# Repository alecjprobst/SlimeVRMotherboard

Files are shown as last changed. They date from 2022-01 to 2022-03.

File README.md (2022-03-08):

# SlimeVR Motherboard

This is a project to make it easier to create SlimeVR trackers. This project reduces the amount of cable management needed when making SlimeVR trackers by providing a PCB that can be made for only $2. Beginner instructions on how to buy a PCB are below. Total cost should be around $55-60 for an enhanced core set excluding the cost of cases and straps.

# Sections

 - Parts and Setup
 - PCB Files and Submission
 - STL Files and Description
 - Assembly Instructions

## Parts and Setup

These PCB's use the official SlimeVR [Components](https://docs.slimevr.dev/diy/components-guide.html) and [Tracker Schematics](https://docs.slimevr.dev/diy/tracker-schematics.html). The PCB is compatible with either the BNO08X or MPU6050 IMU's and has locations for optional Battery Sense resistors and Charge Diodes. With this PCB, you will only need wire for connecting the IMU's. 

All of the parts below are linked in the SlimeVR [Components](https://docs.slimevr.dev/diy/components-guide.html) guide.
This PCB is made for use with the following parts:

 - D1 Mini
 - TP4056 Charging Board (any connector)
 - 3.7V Batteries
 - SS22F32 DPDT Switch
 - Either BNO08X or MPU6050 IMU's
 - (Optional) 180k ohm Battery Sense Resistor
 - (Optional) 1N5817 Charge Diodes

3D printable cases for the SlimeVR Trackers are included in this repo. They require no supports and no hardware to put together. See the STL Files and Description below

## PCB Files

All PCB files are included in this repo in the KiCAD Schematic Folder. Please feel free to modify them as you see fit. KiCAD was use to create this project which is a free and opensource tool to create PCB's. 

## PCB Submission 

Buying a PCB is very simple. Download this repo by clicking the green "Code" button towards the top of this page then click "Download ZIP". You will start downloading a ZIP file contain this entire repo. Open the zip file and find the "SlimeVR Motherboard Gerbers V1.2.rar" and "JLCPCB_Upload_Settings.png" file. Drag these to your desktop or a folder of your choice. 

To buy the PCB, we will use JLC PCB. Their website can be found here: https://jlcpcb.com/. Click on the text that says "Add gerber file" and find and select the "SlimeVR Motherboard Gerbers V1.2.rar" you just moved. Open the "JLCPCB_Upload_Settings.png" file and make sure the settings between the picture and what jlcpcb have shown you are the same. Feel free to change the PCB color to whatever you like (purple looks great!). Click "Save to Cart" then buy your PCB's. This process should be the same as any other online purchase from here on out.

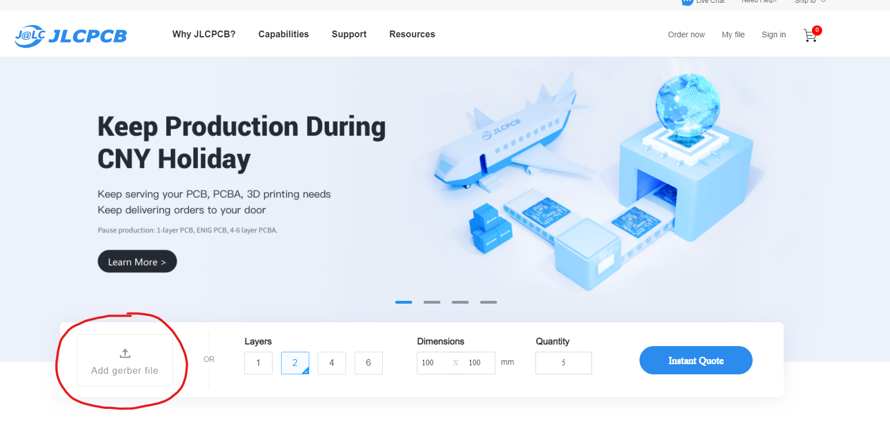
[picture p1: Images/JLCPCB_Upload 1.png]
Images/JPCPCB_Upload 1.png


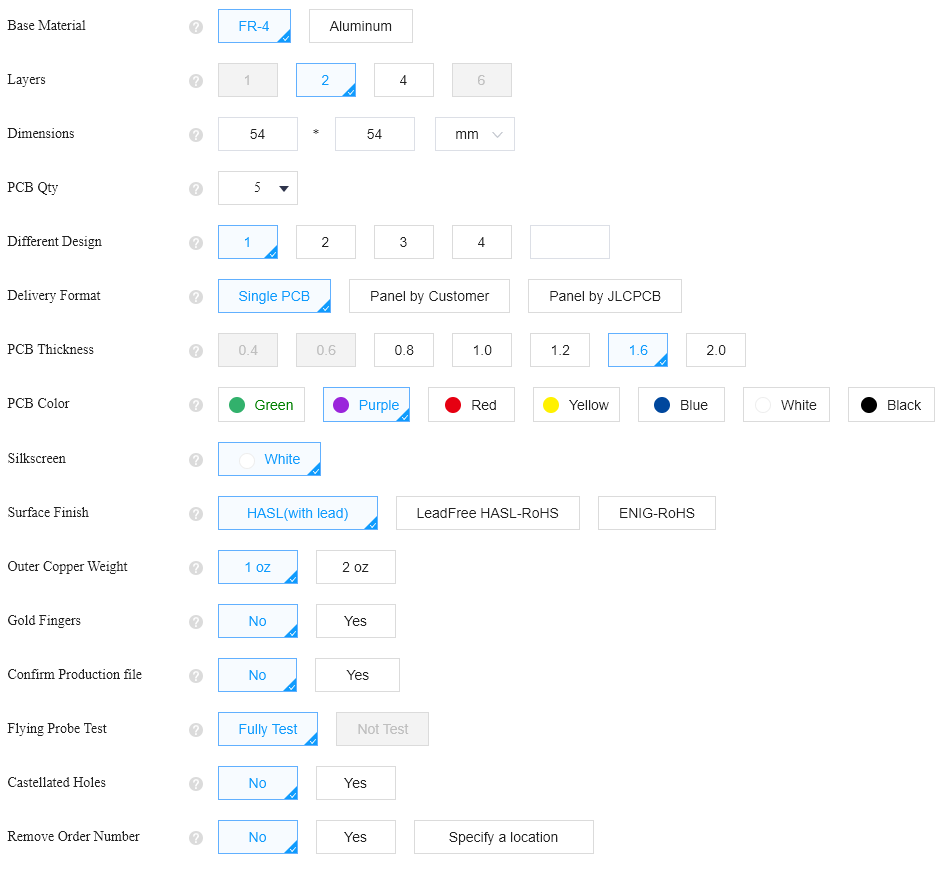
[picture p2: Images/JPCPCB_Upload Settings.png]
Images/JLCPCB_Upload Settings.png


## STL Files and Description

All STL's were created in Fusion360. Please feel free to modify them as you see fit. If you do not have a 3D printer, you can print the cases from jcpcb or you may want to consider 3D printing sites like [Hubs](https://www.hubs.com/3d-printing/) or [Sculpteo](https://www.sculpteo.com/en/).

Cases can be printed on an FDM printer at .2mm layer height.

A single SlimeVR Tracker case requires two parts, a Higher_Body.stl and a Lower_Body.stl. Both of these parts can be printed without supports. The Lower_Body.stl has poles to mount the PCB inside of the case so it does not shake. It is recommended to add hot glue to make sure the PCB does not move at all. Both cases have holes for charging and access to the D1 Mini as well as the switch and AUX tracker cable. The cases should slide together after being printed and should be somewhat difficult to pull apart.

## Assembly Instructions
A Knolled layout of all parts needed for one tracker is shown in this picture. Please note that your IMU's may look different and the resistor and diodes are optional.

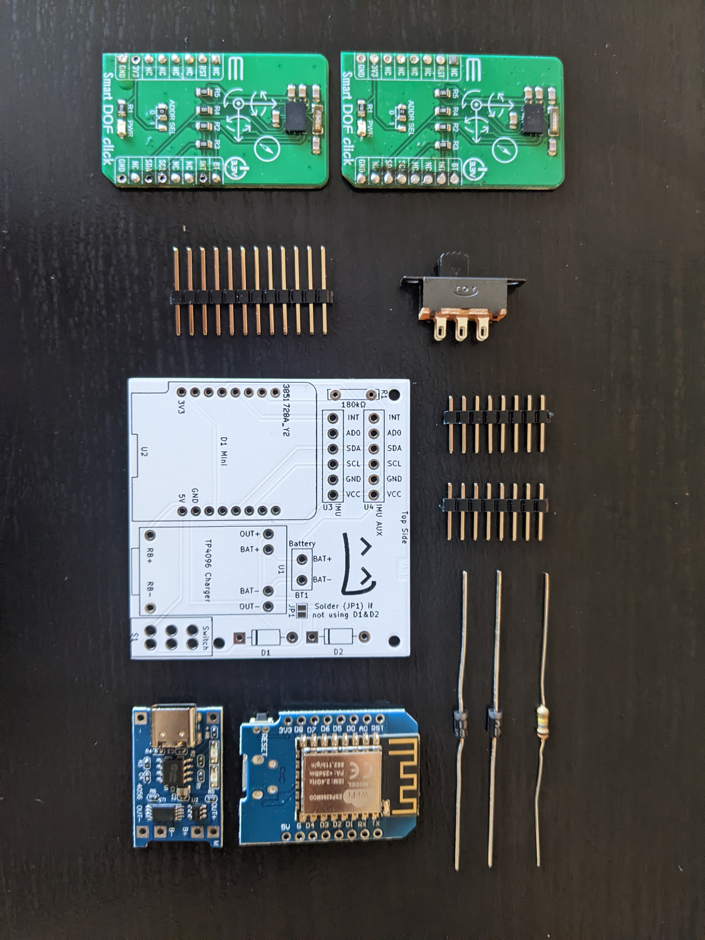
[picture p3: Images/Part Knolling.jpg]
Images/Part Knolling.jpg


To place the resistors, first bend them as shown below

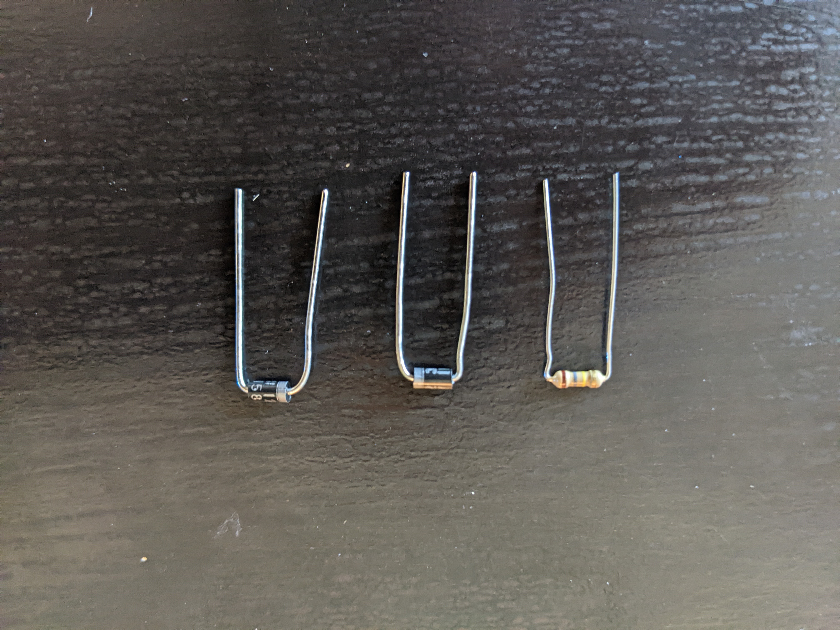
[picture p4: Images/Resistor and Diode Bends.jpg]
Image/Resistor and Diode Bends.jpg


Place these resistor and diodes as such

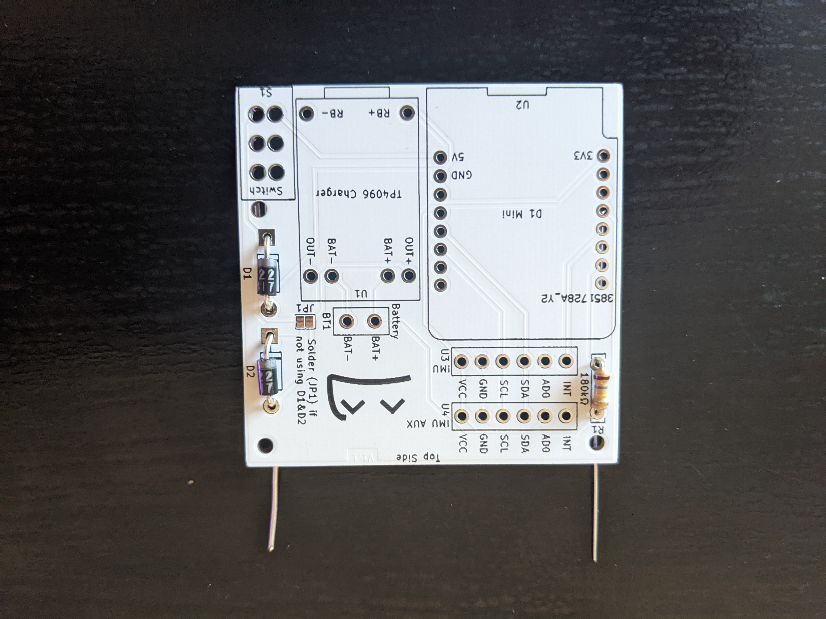
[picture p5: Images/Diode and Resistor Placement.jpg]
Images/Diode and Resistor Placement.jpg


Solder the resistor and diodes as shown in the images below. Cut the excess wire when finished soldering.

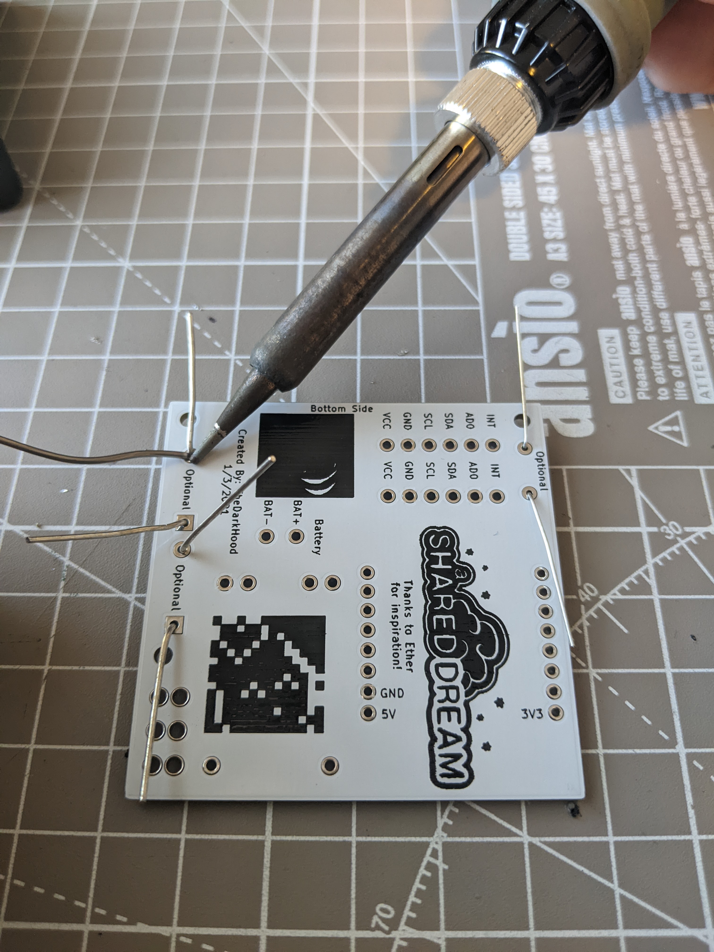
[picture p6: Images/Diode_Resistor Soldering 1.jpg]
Images/Diode_Resistor Soldering 1.jpg


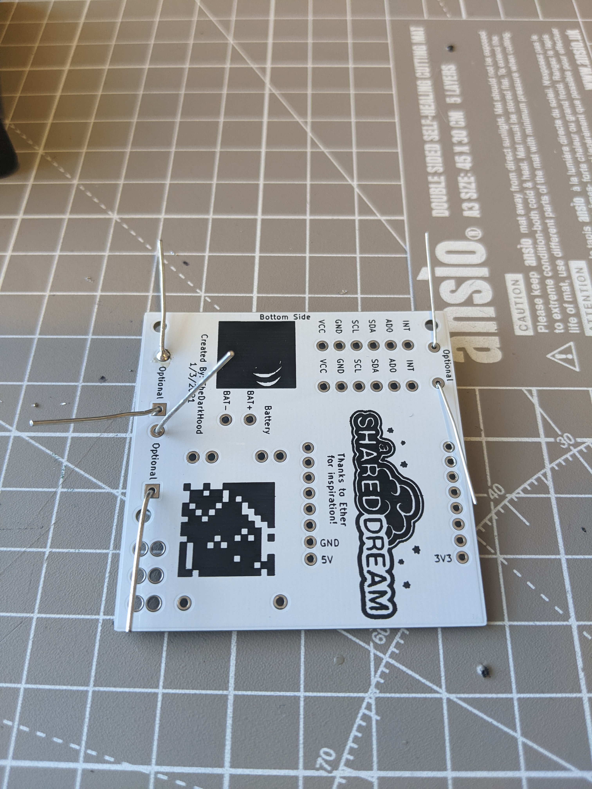
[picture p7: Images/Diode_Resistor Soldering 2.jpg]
Images/Diode_Resistor Soldering 2.jpg


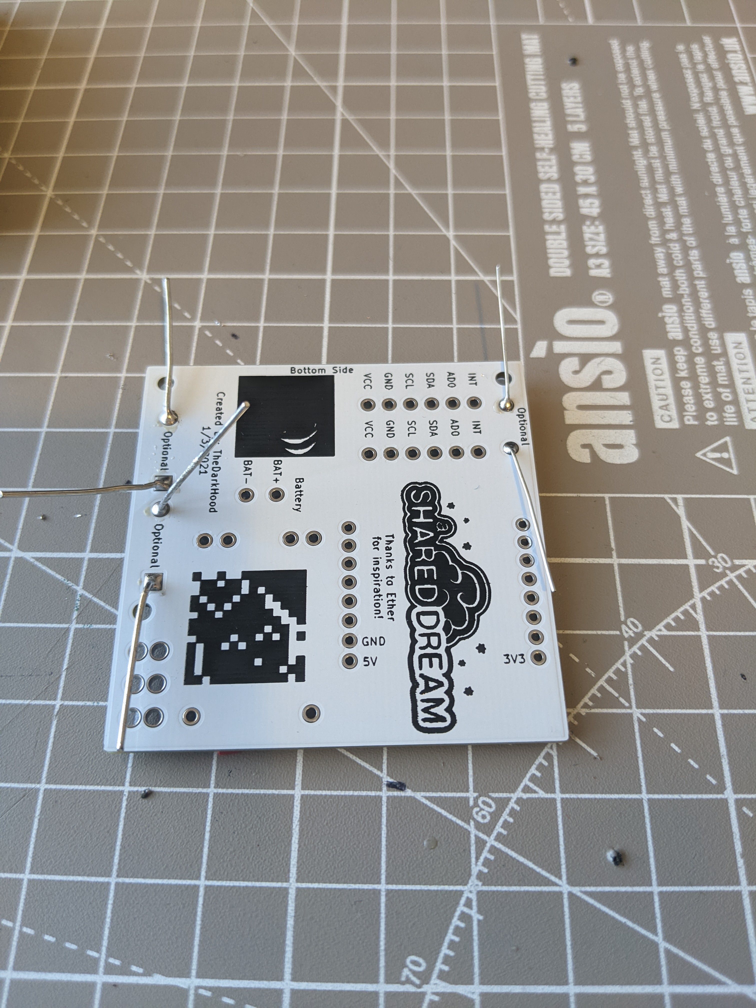
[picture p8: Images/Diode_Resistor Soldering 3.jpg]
Images/Diode_Resistor Soldering 3.jpg


Images/Diode_Resistor Soldering 4.jpg

To solder the TP4096, take 6 pins and place them as such

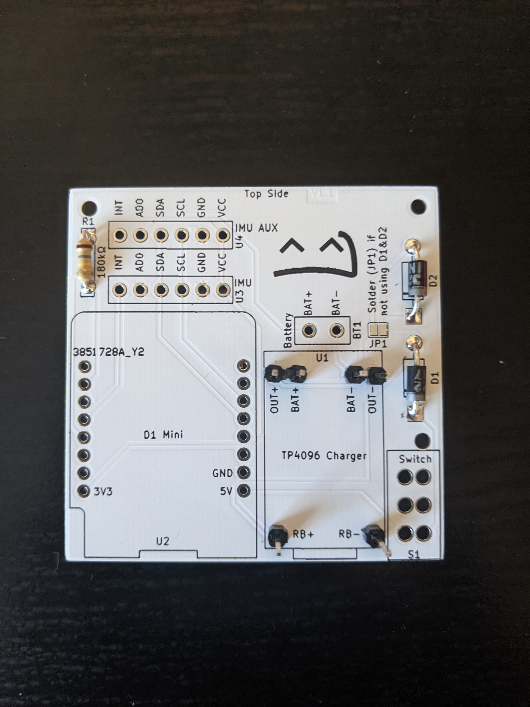
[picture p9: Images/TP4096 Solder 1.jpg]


Solder them on both the top of the TP4096 and the bottom of the PCB as shown below. Cut the excess pins on the top and bottom when finished soldering.

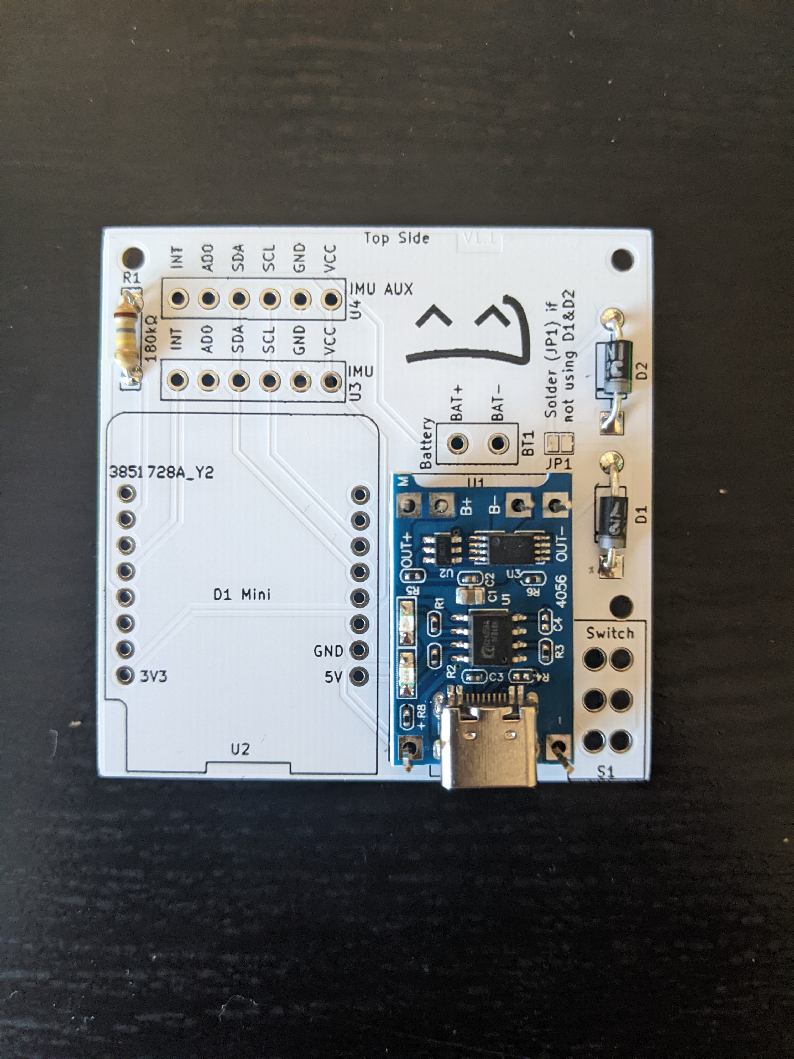
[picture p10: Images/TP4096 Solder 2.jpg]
Images/TP4096 Solder 2.jpg


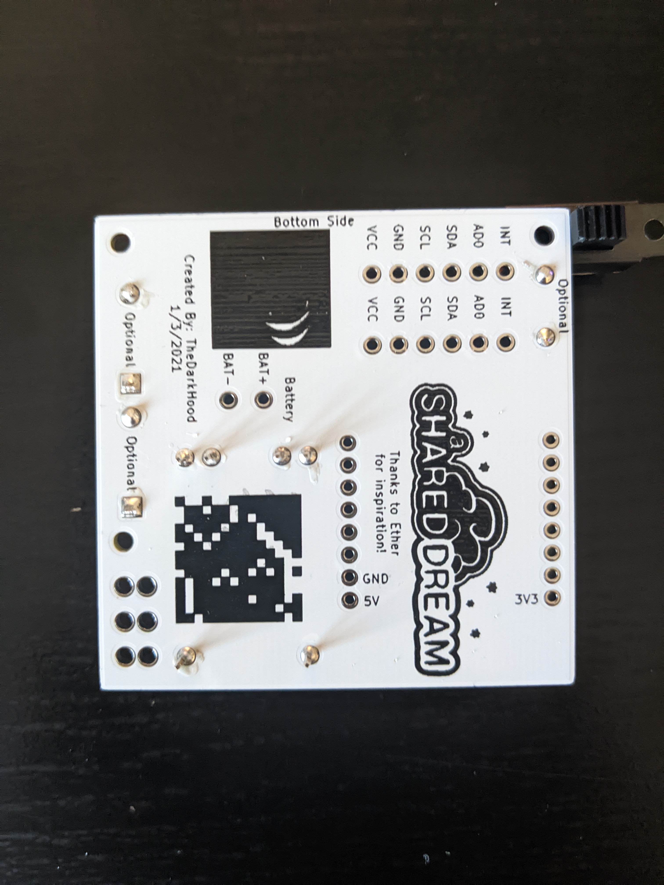
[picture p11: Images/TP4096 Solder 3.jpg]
Images/TP4096 Solder 3.jpg


To solder the D1 Mini, place two 1x8 pins in the holes as shown below.

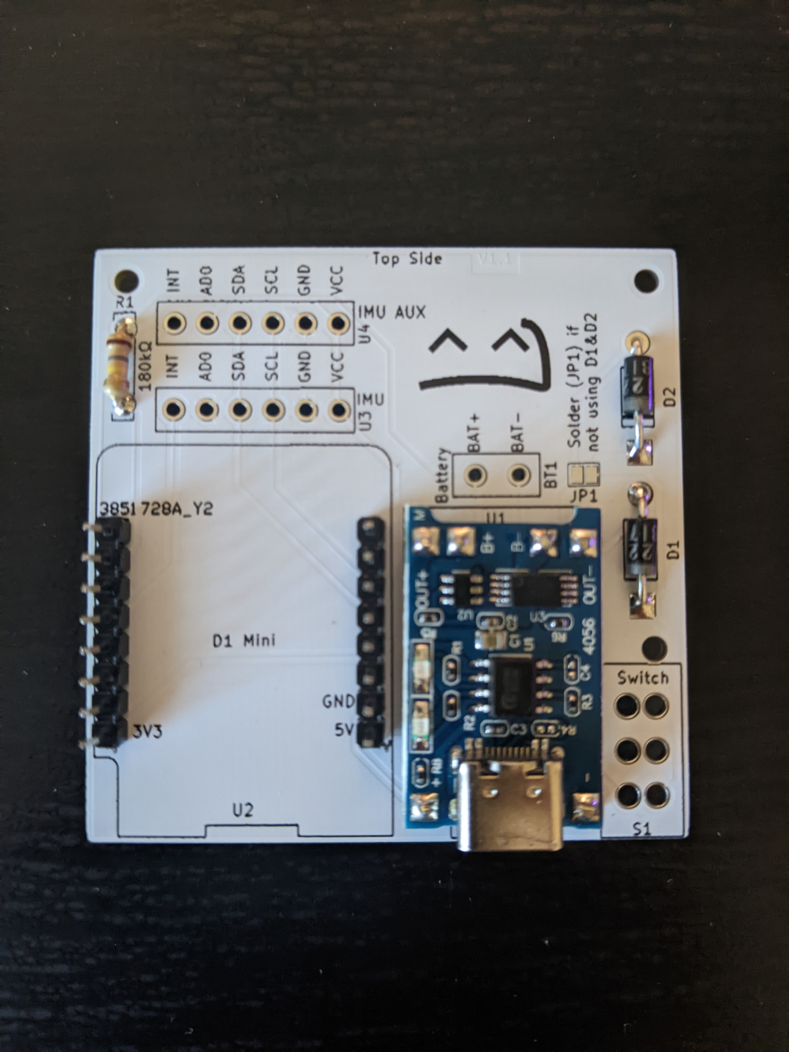
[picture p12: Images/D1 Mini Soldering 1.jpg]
Images/D1 Mini Soldering 1.jpg


Solder the top of the D1 Mini and bottom of the PCB as shown below. Cut the excess pins on the top and bottom when finished soldering.

Images/D1 Mini Soldering 2.jpg

Images/D1 Mini Soldering 3.jpg

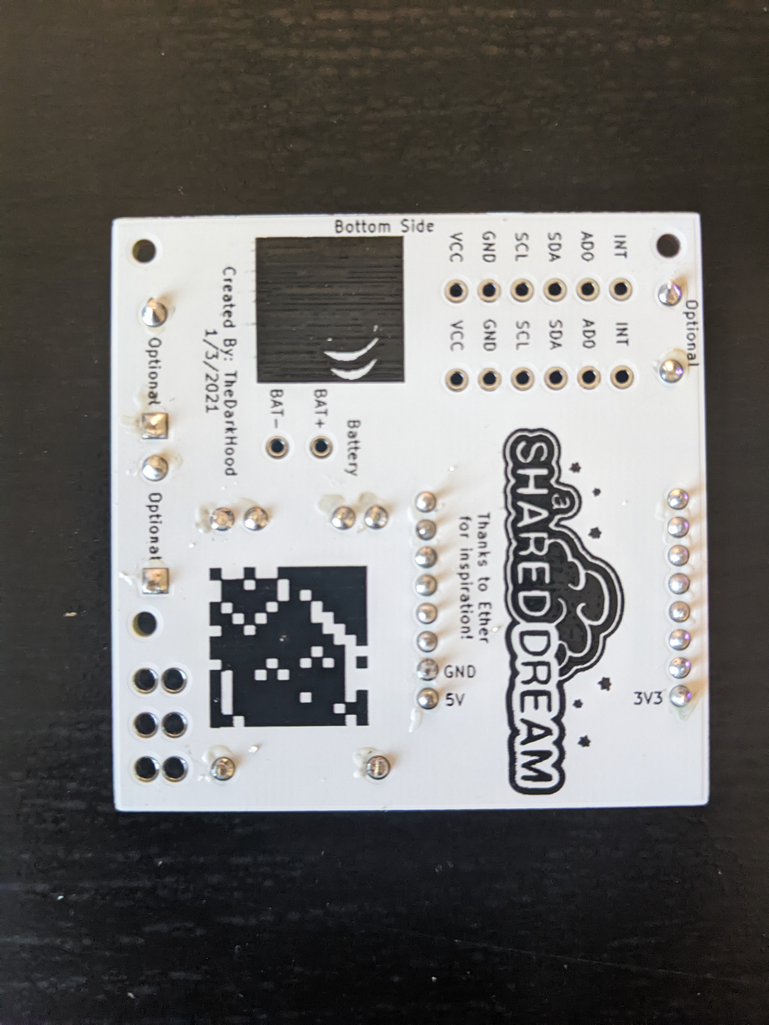
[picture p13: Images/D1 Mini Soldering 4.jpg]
Images/D1 Mini Soldering 4.jpg


Before soldering the switch, cut the excess hole mount as shown in the before and after pictures below.

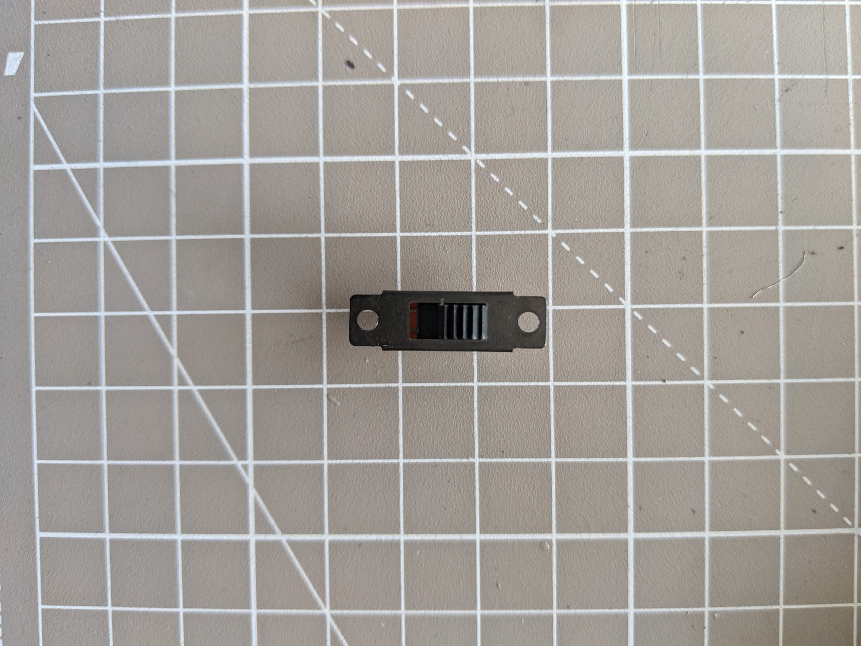
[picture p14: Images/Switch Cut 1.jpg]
Images/Switch Cut 1.jpg


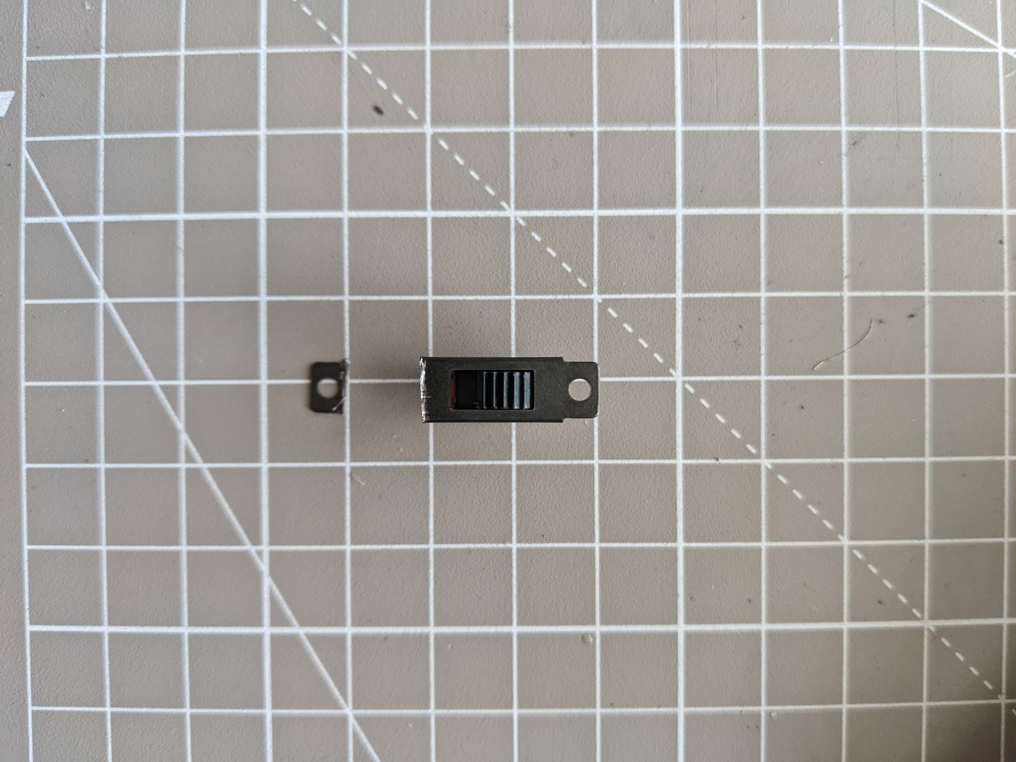
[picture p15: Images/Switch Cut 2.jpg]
Images/Switch Cut 2.jpg


To keep the Switch in place, it is recommended to use tape as shown below. Once secured, solder the switch from the bottom of the PCB. Cut the excess switch contacts after soldering

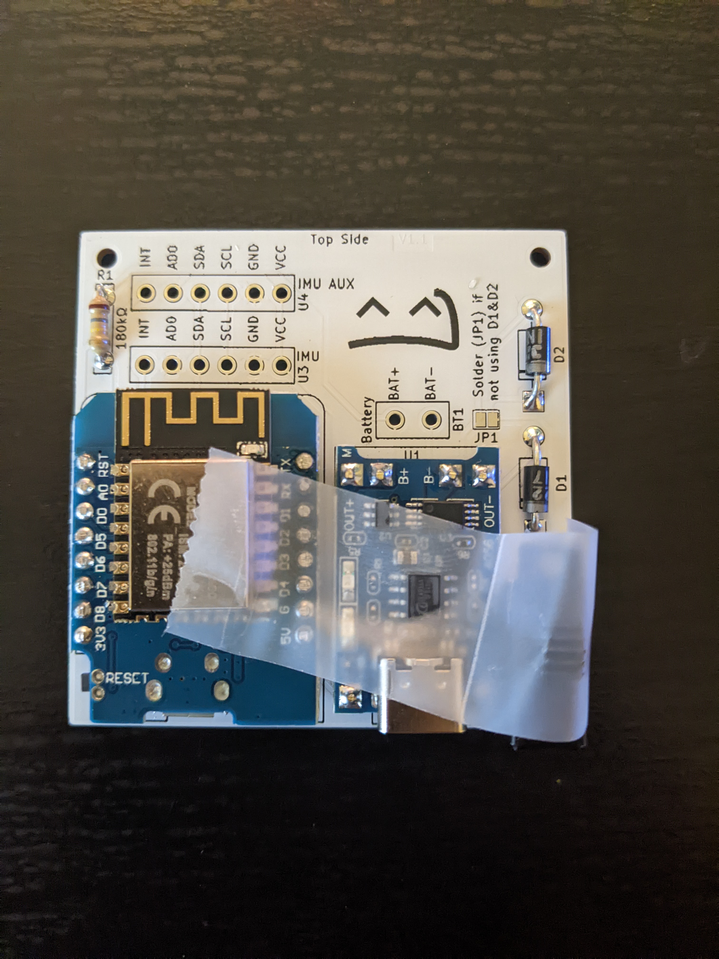
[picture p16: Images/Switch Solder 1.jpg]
Images/Switch Solder 1.jpg


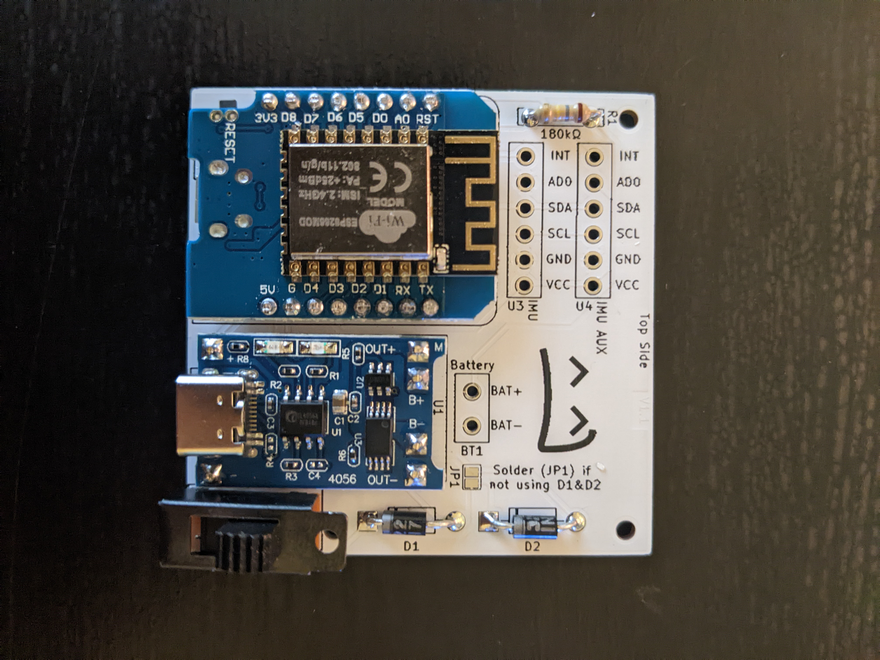
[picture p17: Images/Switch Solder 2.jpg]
Images/Switch Solder 2.jpg


To add the IMU, first cut out 6 wires of around 25mm long and strip the ends of the wires as shown below.

Images/IMU Wiring.jpg

Solder the wires as shown below. Generally it is easier to solder to the PCB first then the IMU but this may be personal preference. Cut the excess wire after soldering. Note: the AD0 wire is missing in the two pictures below and is required.

Images/IMU Soldering 1.jpg

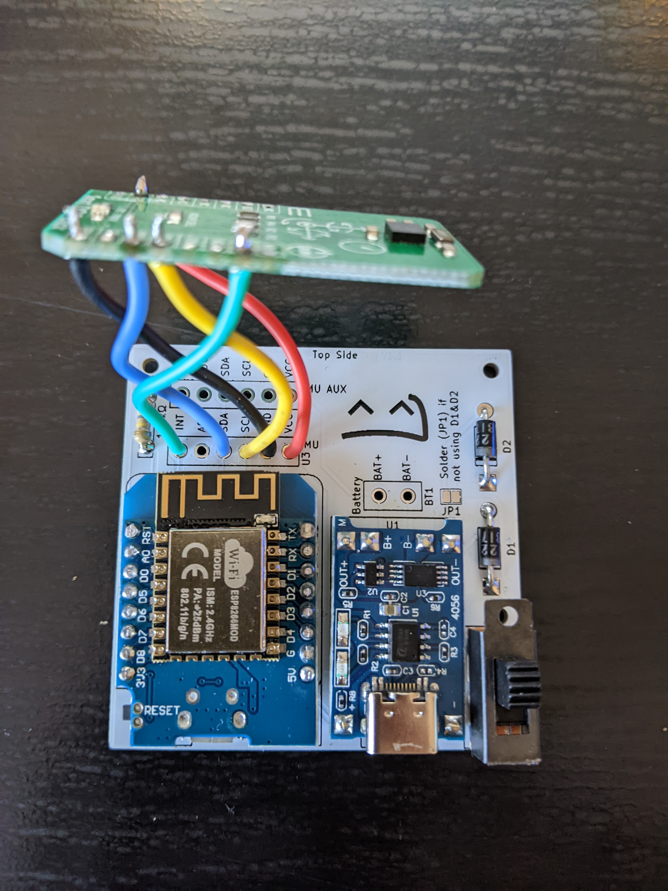
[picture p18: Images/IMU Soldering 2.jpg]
Images/IMU Soldering 2.jpg


To Solder the AUX IMU, cut out 6 wires of either 150mm or 300mm in length. The 150mm is used for the ankle/foot IMU's while the 300mm is used for the chest/wait IMU's.

Images/AUX IMU Wiring.jpg

Solder the AUX IMU as shown below. Cut the excess wires after soldering.

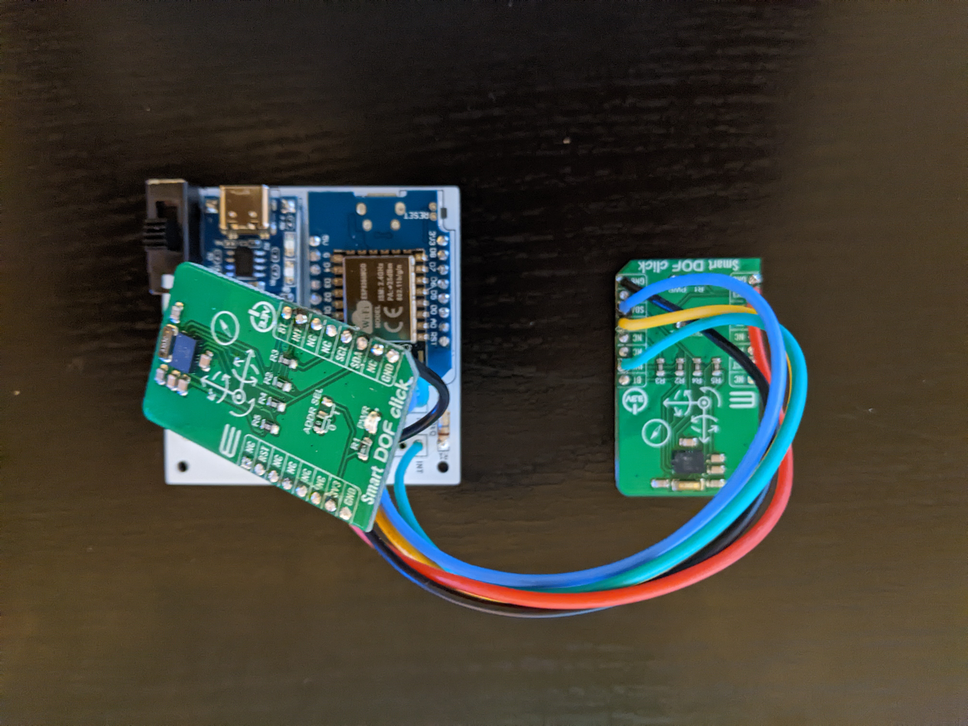
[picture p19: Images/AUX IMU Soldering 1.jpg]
Images/AUX IMU Soldering 1.jpg


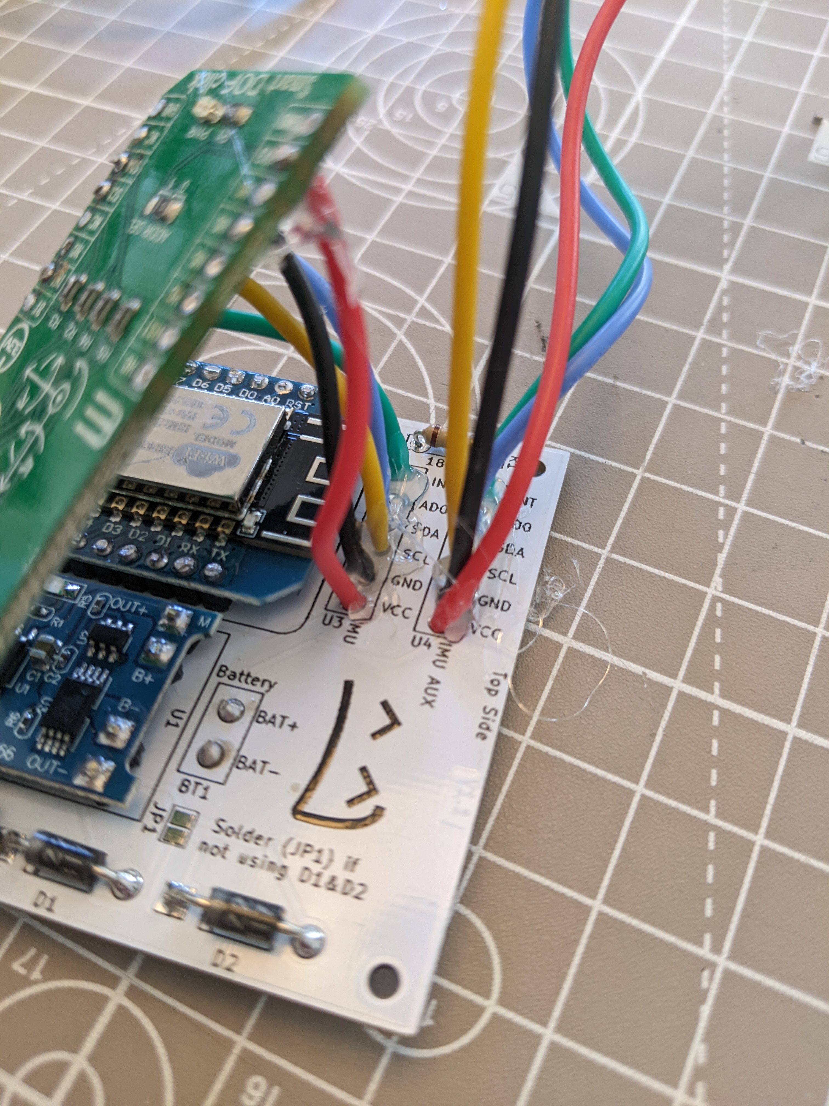
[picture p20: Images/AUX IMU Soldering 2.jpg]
Images/AUX IMU Soldering 2.jpg


To solder the battery, solder the ground (black) wire first then the power (red) wire second from the bottom of the PCB. Make sure these wires do not touch as it may cause sparks. Cut the excess wire when finished soldering.

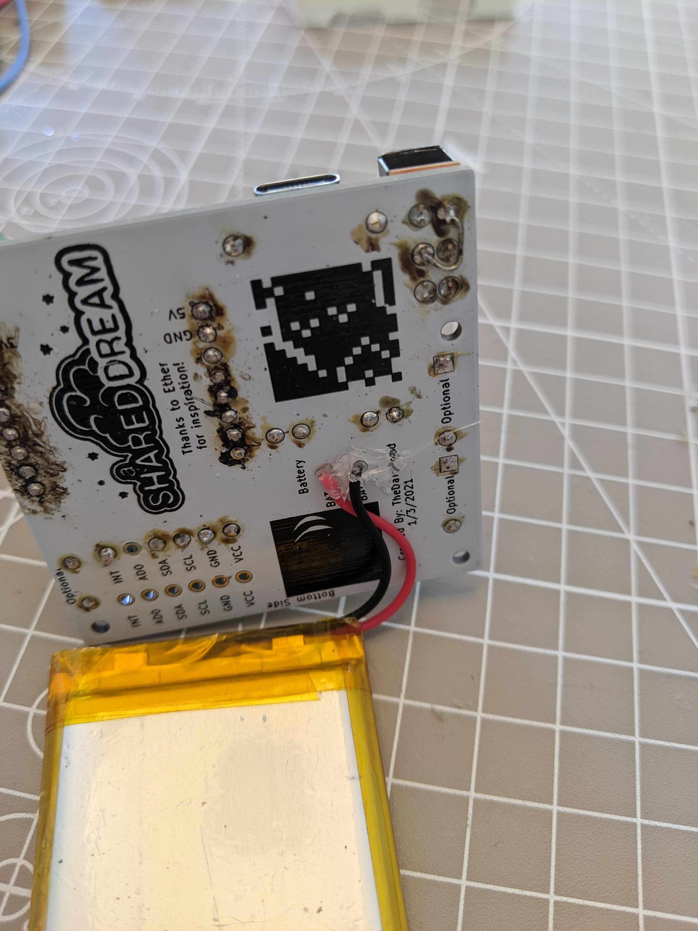
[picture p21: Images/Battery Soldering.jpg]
Images/Battery Soldering.jpg


It is recommended but not required to hot glue all parts as to prevent parts from moving inside the case. Hot gluing the wires will help protect from from strain as well. To assemble the case, put the battery in the Lower Body first.

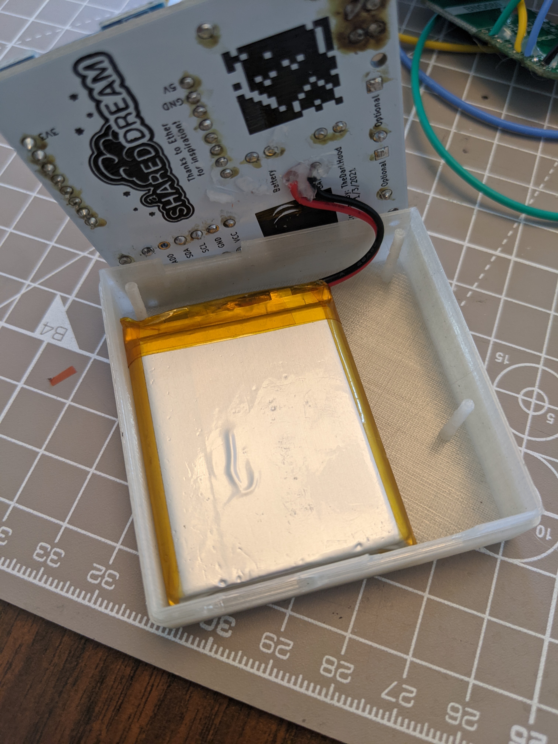
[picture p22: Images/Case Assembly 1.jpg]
Images/Case Assembly 1.jpg


Next, put the PCB on top of the battery with the ports facing the holes. The holes in the PCB should keep the PCB in place. Make sure that there are no excess wires or pins poking into the battery.

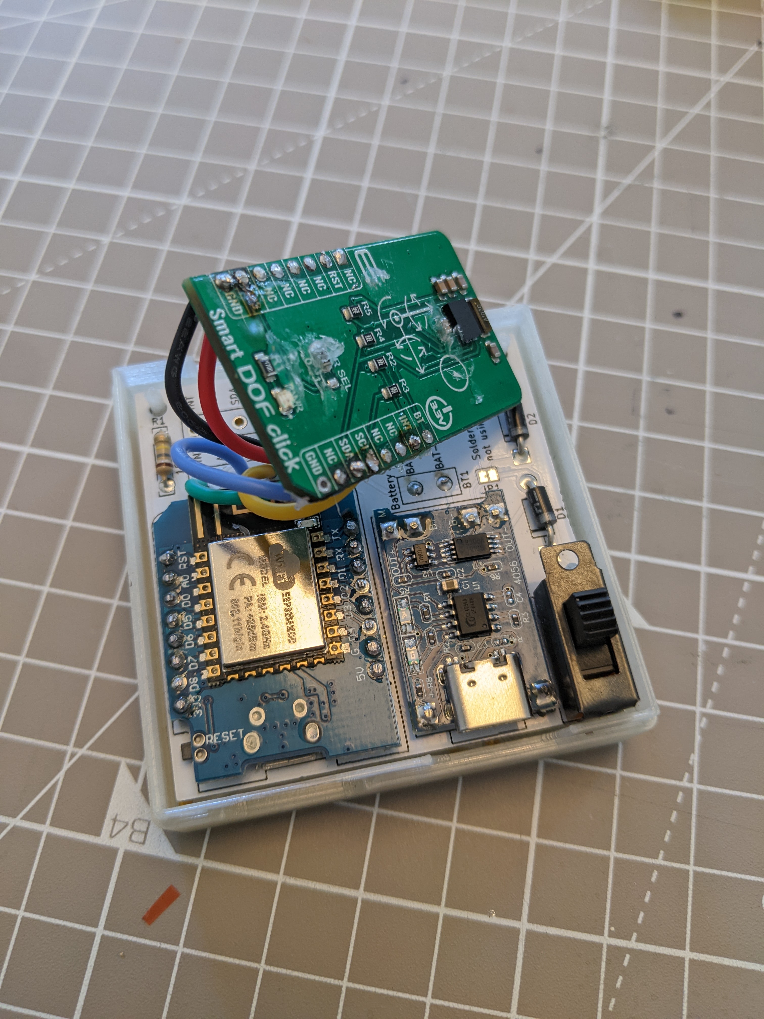
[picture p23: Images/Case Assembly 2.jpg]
Images/Case Assembly 2.jpg


Hot glue the IMU to the Higher Body Case. Make sure the Higher Body Case is lined up correctly so the holes are facing the correct direction. 

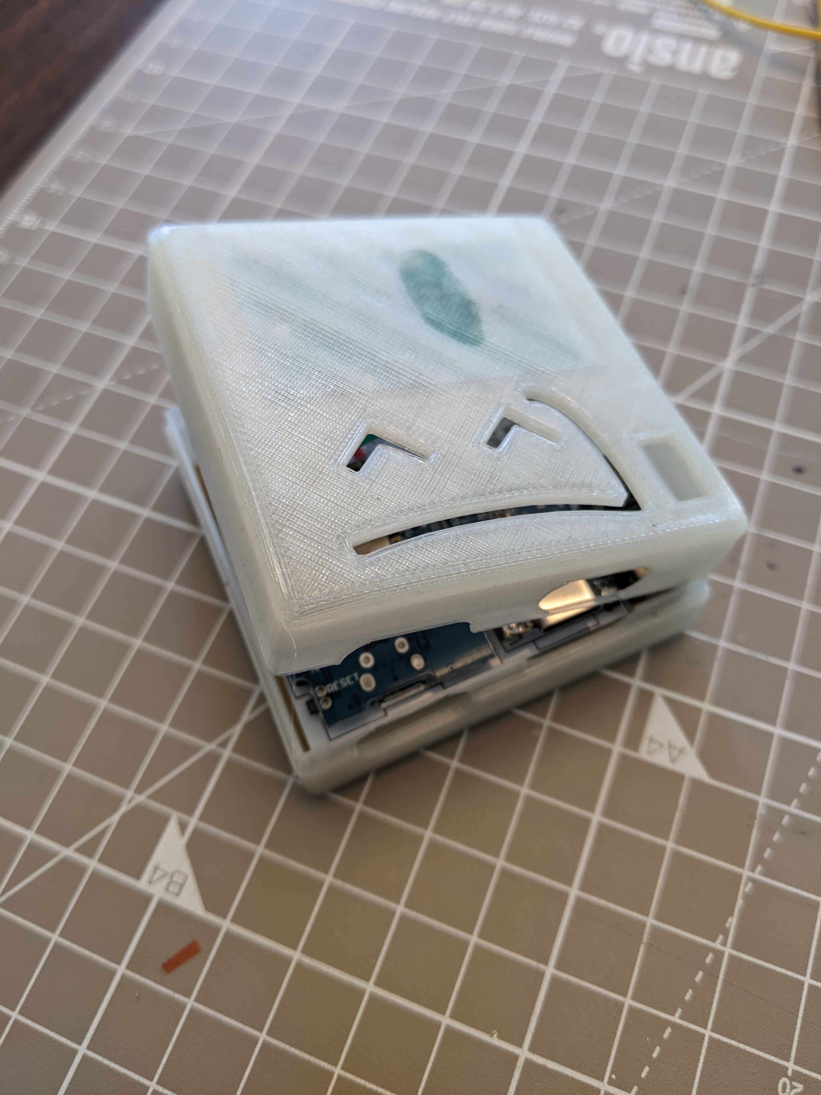
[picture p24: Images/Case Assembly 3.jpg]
Images/Case Assembly 3.jpg


Slide the Higher Body Case onto the Lower Body Case to close the SlimeVR Tracker. Make sure no wires get pinched or disconnected and the switch is able to be turned off and on. This completes the hardware assembly of the SlimeVR trackers. To setup the software, continue from the [SlimeVR Tracker Firmware Guide](https://docs.slimevr.dev/firmware/updating-firmware.html)

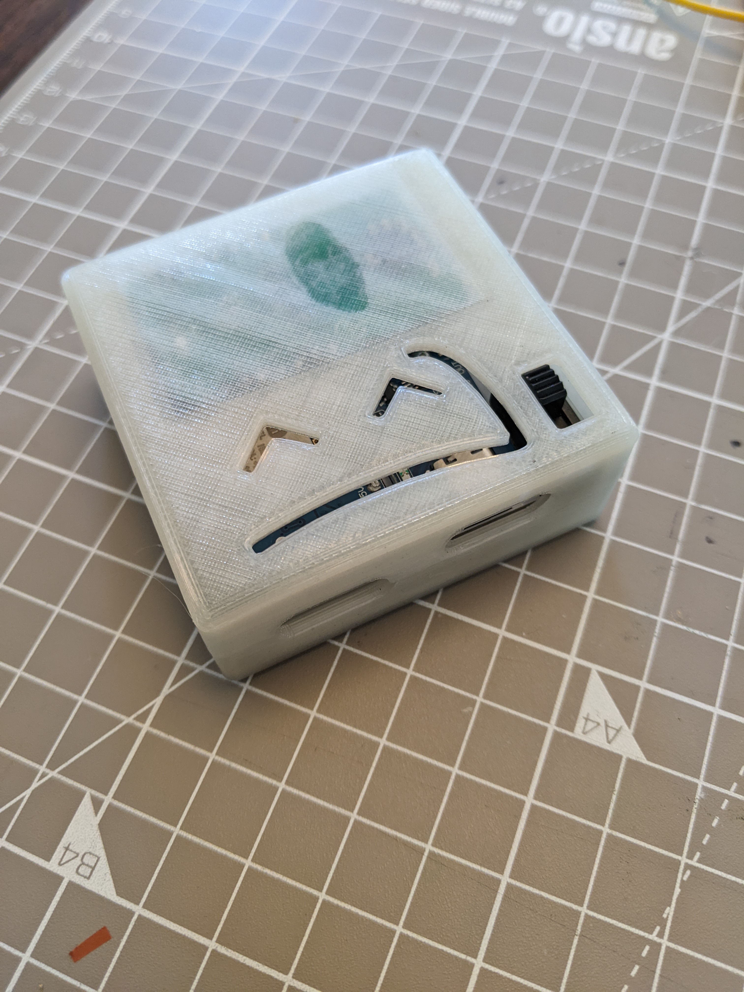
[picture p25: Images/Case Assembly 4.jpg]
Images/Case Assembly 4.jpg


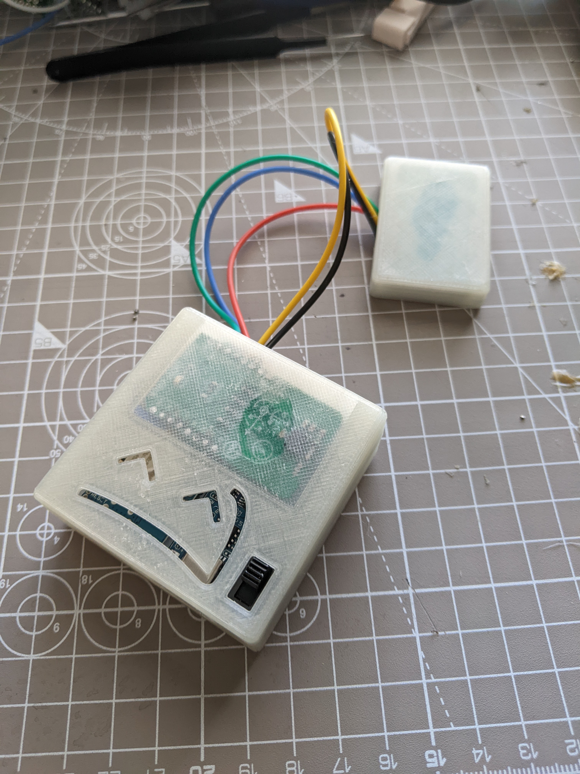
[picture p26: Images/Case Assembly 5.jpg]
Images/Case Assembly 5.jpg


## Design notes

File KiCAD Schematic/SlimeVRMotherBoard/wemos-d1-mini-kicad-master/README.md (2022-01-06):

 wemos-d1-mini-kicad
==============
KiCAD

* library, 
* footprint and 
* 3D shape 

of the WeMos D1 mini board. 

The library provides several footprints and shape alignments:

butler 3d view
butler 3d view
butler 3d view
butler 3d view

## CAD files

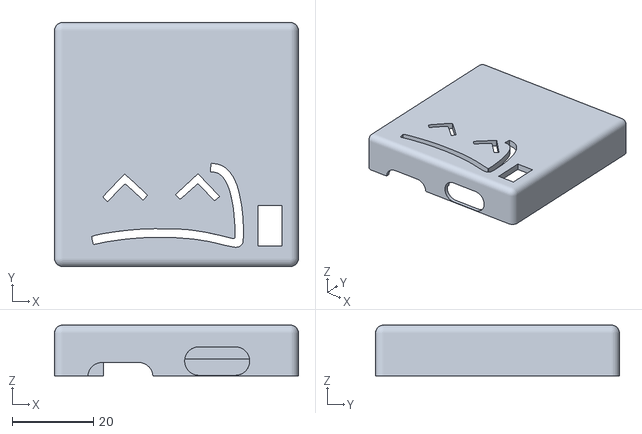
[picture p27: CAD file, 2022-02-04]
STL Files/Higher_Body.stl
60.0 x 60.0 x 12.5

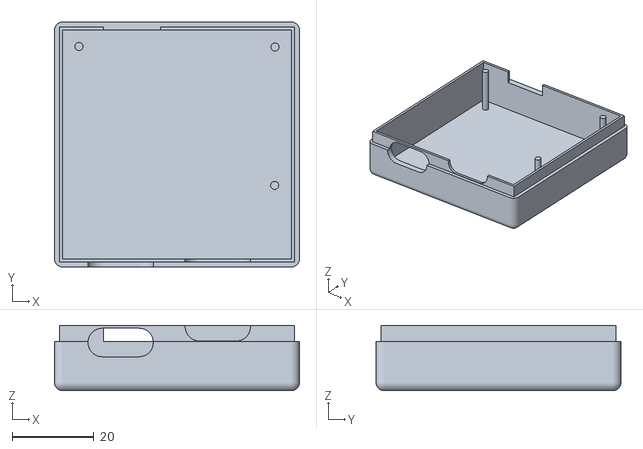
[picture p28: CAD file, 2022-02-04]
STL Files/Lower_Body.stl
60.0 x 60.0 x 16.0

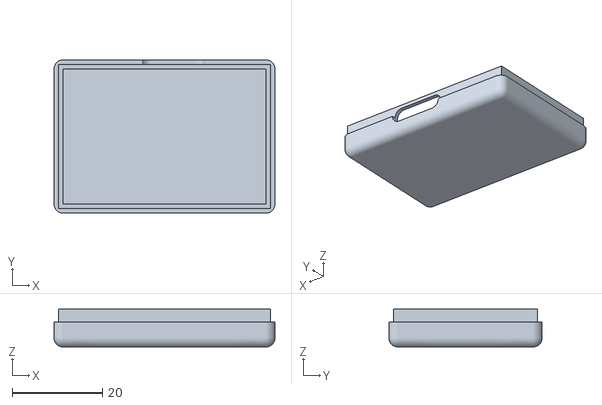
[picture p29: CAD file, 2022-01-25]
STL Files/Lower_Body_IMU.stl
49.0 x 34.0 x 8.40

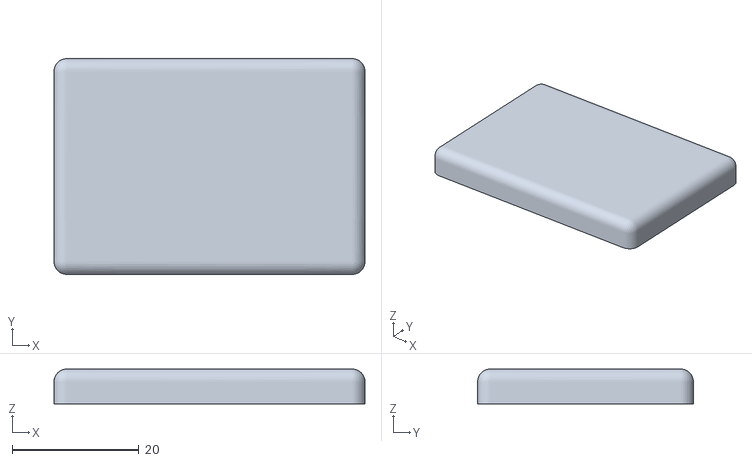
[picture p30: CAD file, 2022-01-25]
STL Files/Higher_Body_IMU.stl
49.0 x 34.0 x 5.50

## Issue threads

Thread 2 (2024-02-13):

Suggestion for plugs

Sacred-Shadow, 2024-02-13:
Thank you for the excellent guide and the really good motherboard. 👍🏻

One thing I have is, could you possibly offer the motherboard in a version where a JST connector fits?
Especially for the IMU connection, that would be great. Currently, it doesn't fit due to the hole spacing.

alecjprobst, 2024-02-14:
I'm afraid I don't have time to do this currently, the KiCAD files should allow you to make that change very easily though. The JST connector may not fit inside of the case however.

Closed 2024-02-14.

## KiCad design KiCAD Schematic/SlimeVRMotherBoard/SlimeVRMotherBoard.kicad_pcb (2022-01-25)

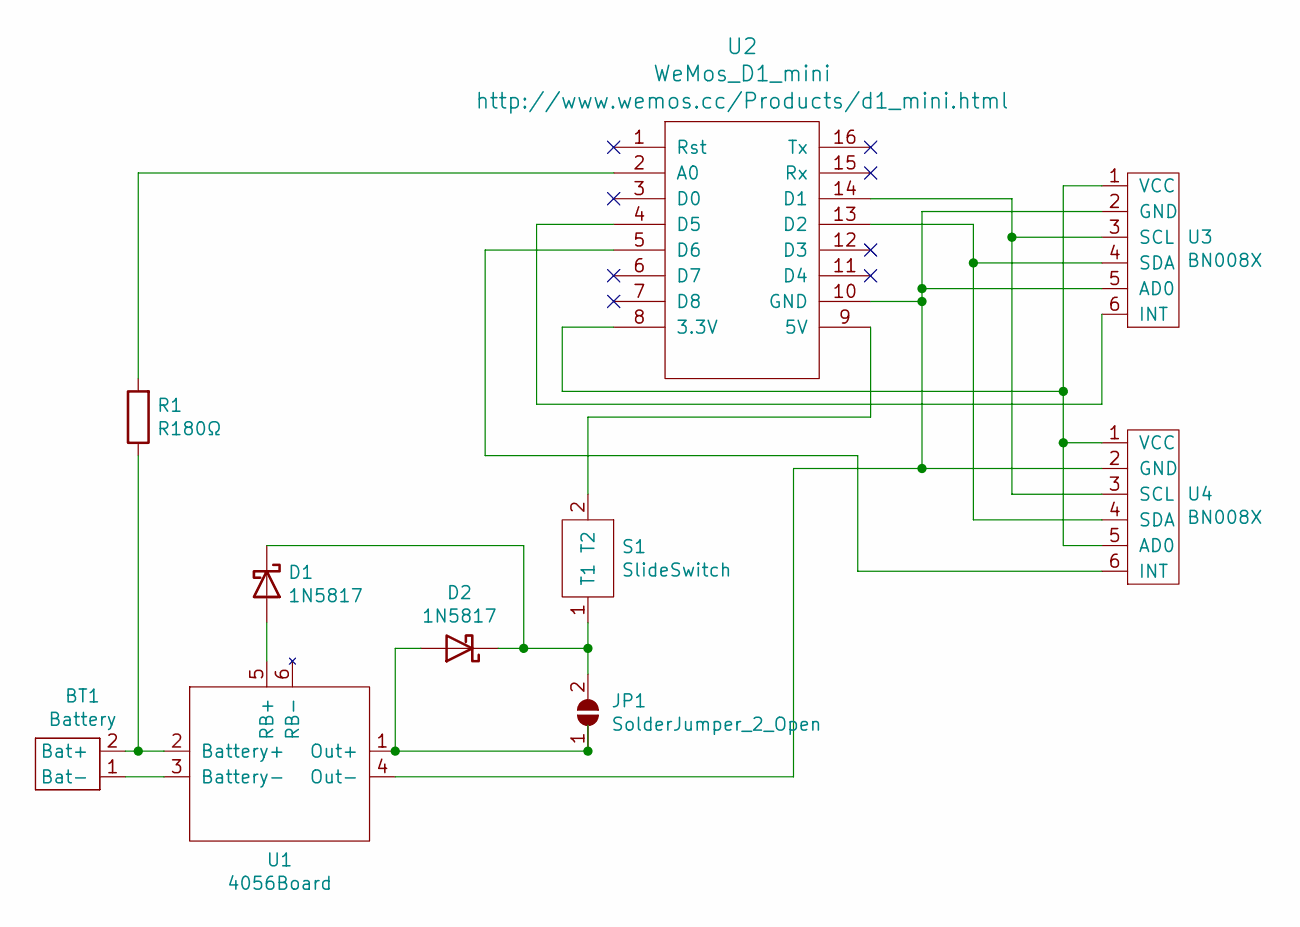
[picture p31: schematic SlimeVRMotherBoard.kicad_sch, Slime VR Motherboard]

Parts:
BT1: Battery
D1, D2: 1N5817; D_DO-41_SOD81_P10.16mm_Horizontal
JP1: SolderJumper_2_Open; SolderJumper-2_P1.3mm_Open_Pad1.0x1.5mm
R1: R180Ω; 180KΩ
S1: SlideSwitch; SS22F32
U1: 4056Board
U2: WeMos_D1_mini; wemos-d1-mini-connectors-only
U3, U4: BN008X; BNO080_Connector

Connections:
unnamed: BT1.1 (Bat-), U1.3 (Battery-)
unnamed: BT1.2 (Bat+), R1.1, U1.2 (Battery+)
unnamed: D1.1 (K), D2.1 (K), JP1.2 (B), S1.1 (T1)
unnamed: D1.2 (A), U1.5 (RB+)
unnamed: D2.2 (A), JP1.1 (A), U1.1 (Out+)
unnamed: R1.2, U2.2 (A0)
unnamed: S1.2 (T2), U2.9 (5V)
unnamed: U1.4 (Out-), U2.10 (GND), U3.2 (GND), U3.5 (AD0), U4.2 (GND)
unnamed: U2.4 (D5), U3.6 (INT)
unnamed: U2.5 (D6), U4.6 (INT)
unnamed: U2.8 (3.3V), U3.1 (VCC), U4.1 (VCC), U4.5 (AD0)
unnamed: U2.13 (D2), U3.4 (SDA), U4.4 (SDA)
unnamed: U2.14 (D1), U3.3 (SCL), U4.3 (SCL)

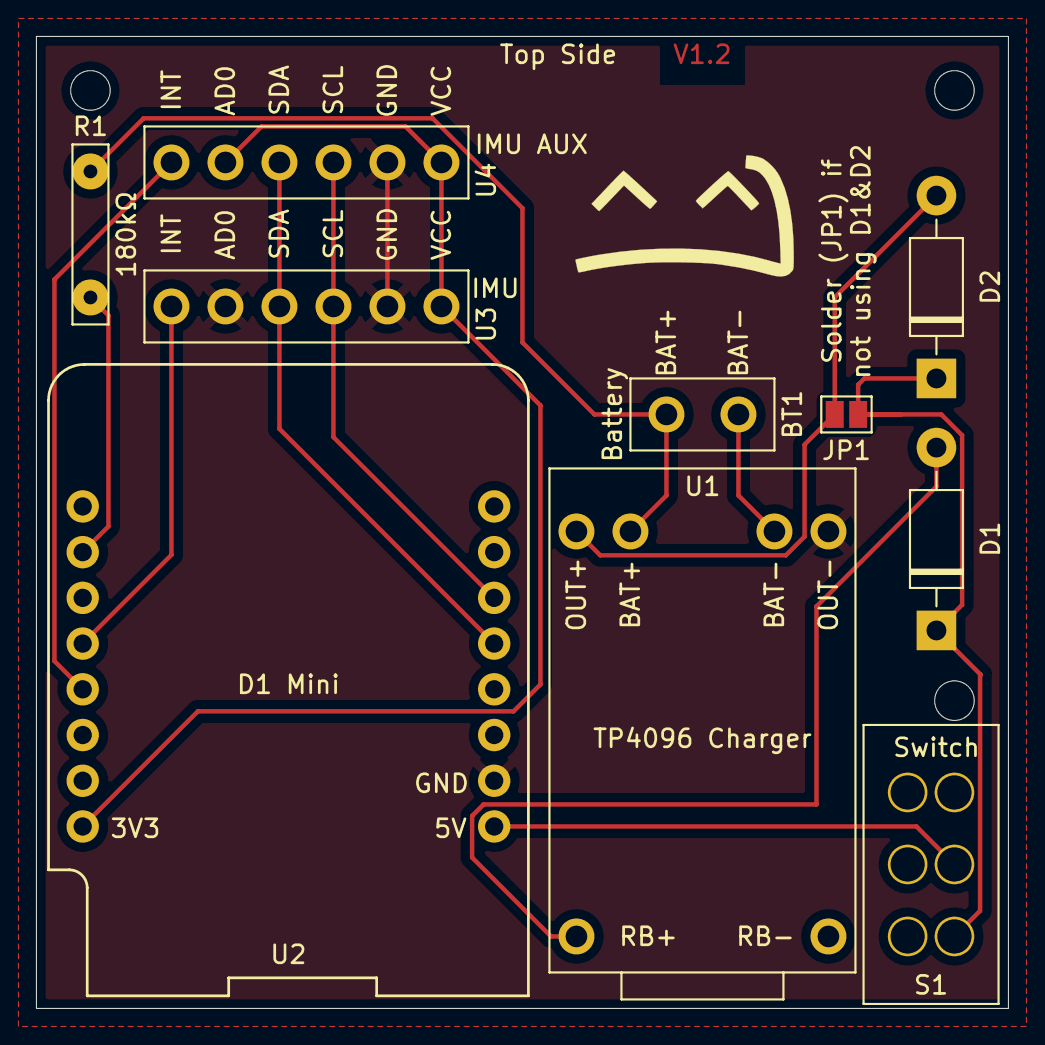
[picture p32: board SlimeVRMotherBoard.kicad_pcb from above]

Board: 2 copper layers, 54.0 x 54.0 mm, 10 parts (0 on the bottom side), 13 nets.

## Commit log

2022-01-06 Initial Submission
    [Higher_Body.stl, Lower_Body.stl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]
2022-01-25 Updated board to V1.2 that fixed switch issue. Added new stl's for IMU cases
    [Higher_Body_IMU.stl, Lower_Body_IMU.stl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]
2022-02-04 Increase height of higher and lower body to fit trackers. Added pictures of build process
    [Higher_Body_IMU.stl, Lower_Body.stl]
2022-02-06 Fixed accidentally swapped Higher_Body and Higher_Body_IMU files
    [Higher_Body.stl, Higher_Body_IMU.stl]

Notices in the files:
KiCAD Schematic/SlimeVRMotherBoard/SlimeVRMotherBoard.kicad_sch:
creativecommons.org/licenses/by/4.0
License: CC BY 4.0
